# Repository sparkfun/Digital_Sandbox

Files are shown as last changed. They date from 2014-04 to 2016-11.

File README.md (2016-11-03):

Digital_Sandbox
===============

SparkFun Digital Sandbox

[*SparkFun Digital Sandbox (SKU)*](https://www.sparkfun.com/products/12651)

he Digital Sandbox (DS) is a learning platform that engages both the software and hardware worlds.
It’s powered by a microcontroller that can interact with real-world inputs – like light or temperature sensors – while simultaneously controlling LEDs, motors, and other outputs. 

Repository Contents
-------------------

* **/Documentation** - Data files for the Digital Sandbox booklet
* **/Firmware** - Example code for the Digital Sandbox experiment guide
* **/Hardware** - Eagle design files (.brd, .sch)
* **/Production** - Production panel files (.brd)

Documentation
--------------
* **[Hookup Guide](https://learn.sparkfun.com/tutorials/digital-sandbox-arduino-companion)** - Basic hookup guide for the Digital SandBox.
* **[SparkFun Fritzing repo](https://github.com/sparkfun/Fritzing_Parts)** - Fritzing diagrams for SparkFun products.
* **[SparkFun 3D Model repo](https://github.com/sparkfun/3D_Models)** - 3D models of SparkFun products.
* **[SparkFun Graphical Datasheets](https://github.com/sparkfun/Graphical_Datasheets)** -Graphical Datasheets for various SparkFun products.

License Information
-------------------

This product is _**open source**_!

Please review the LICENSE.md file for license information.

If you have any questions or concerns on licensing, please contact techsupport@sparkfun.com.

Distributed as-is; no warranty is given.

- Your friends at SparkFun.

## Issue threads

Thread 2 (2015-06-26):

AREF line is tied directly to battery in

bhuang10000, 2015-06-26:
AREF line is tied directly to the battery IN and the charging circuit. This causes anomalies with the A\D. Suggest tying this to the 3.3V VReg.

ToniCorinne, 2015-06-29:
Since you're internal, please file this as a revision request in Bugzilla. It'll make it easier for us to track that this change has been requested.

Closed 2015-06-29.

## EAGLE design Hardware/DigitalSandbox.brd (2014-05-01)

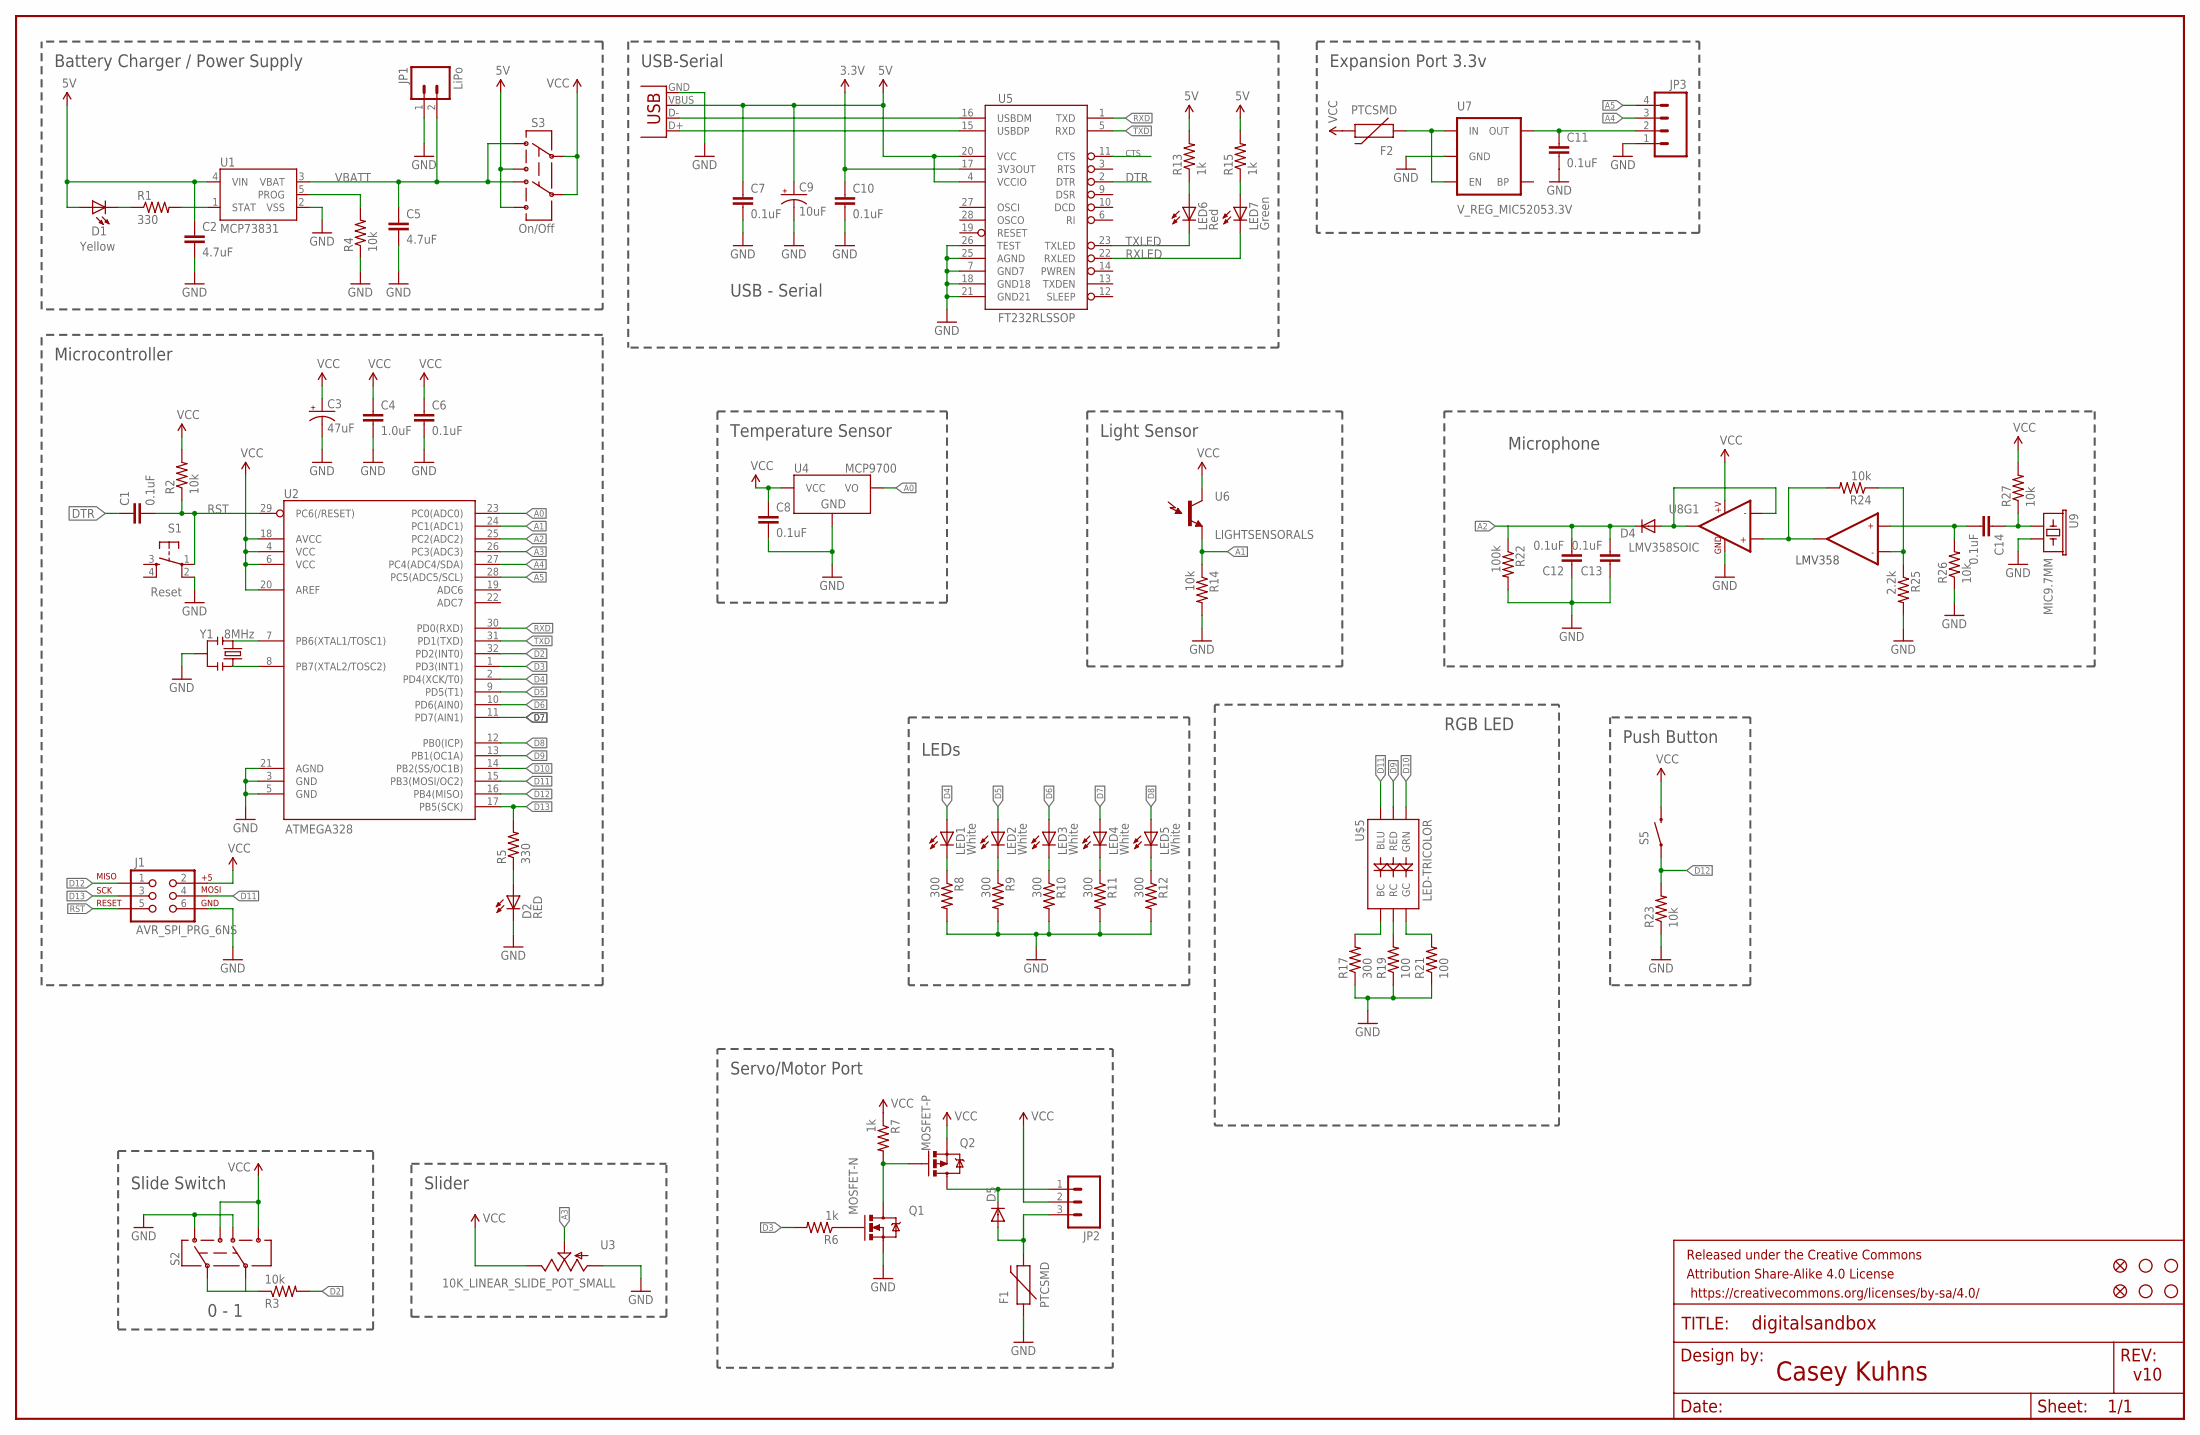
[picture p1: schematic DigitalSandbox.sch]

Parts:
C1, C6, C7, C8, C10, C11, C12, C13, C14: 0.1uF; 0603-CAP
C2, C5: 4.7uF; 0603-CAP
C3: 47uF; EIA3528
C4: 1.0uF; 0603-CAP
C9: 10uF; EIA3216
D1: Yellow; LED-0603
D2: RED; LED-1206
D4, D5: DIODESOD; SOD-323
F1, F2: PTCSMD; PTC-1206
FID1, FID2: FIDUCIAL1X2; FIDUCIAL-1X2
FRAME1: FRAME-LEDGER; CREATIVE_COMMONS
J1: AVR_SPI_PRG_6NS; 2X3-NS
JP1: LiPo; JST-2-SMD
JP2: M03SMD_RA_FEMALE; 1X03_SMD_RA_FEMALE
JP3: M04SMD_STRAIGHT_COMBO; 1X04_SMD_STRAIGHT_COMBO
LED1, LED2, LED3, LED4, LED5: White; LED-1206
LED6: Red; LED-0603
LED7: Green; LED-0603
Q1: MOSFET-N; SOT23
Q2: MOSFET-P; SOT23-3
R1, R5: 330; 0603-RES
R2, R3, R4, R14, R23, R24, R26, R27: 10k; 0603-RES
R6, R7, R13, R15: 1k; 0603-RES
R8, R9, R10, R11, R12, R17: 300; 0603-RES
R19, R21: 100; 0603-RES
R22: 100k; 0603-RES
R25: 2.2k; 0603-RES
S1: Reset; TACTILE_SWITCH_SMD
S2: SWITCH-DPDTAYZ0202; AYZ0202
S3: On/Off; AYZ0202
S5: SWITCH-MOMENTARY-2SMD-4; TACTILE_SWITCH_TALL
STANDOFF1, STANDOFF2, STANDOFF3, STANDOFF4: STAND-OFF
U1: MCP73831; SOT23-5
U2: ATMEGA328; TQFP32-08
U3: 10K_LINEAR_SLIDE_POT_SMALL; C2031N-1A2-B10K-GP
U4: MCP9700; SOT23-3
U5: FT232RLSSOP; SSOP28DB
U6: LIGHTSENSORALS; ALS-PT19
U7: V_REG_MIC52053.3V; SOT23-5
U8: LMV358SOIC; SO08
U9: MIC9.7MM; MIC-9.7MM
U$5: LED-TRICOLOR; PLCC-6-LED
X1: USBSMD; USB-MINIB
Y1: 8MHz; RESONATOR-SMD

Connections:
3.3V: C10.1, U5.17 (3V3OUT)
5V: C2.1, C7.1, C9.A (+), D1.A, R13.2, R15.2, S3.3, S3.6, U1.4 (VIN), U5.4 (VCCIO), U5.20 (VCC), X1.VBUS
A0: U2.23 (PC0(ADC0)), U4.2 (VO)
A1: R14.1, U2.24 (PC1(ADC1)), U6.E (E1)
A2: C12.2, C13.2, D4.C, R22.1, U2.25 (PC2(ADC2))
A3: U2.26 (PC3(ADC3)), U3.1 (S)
A4: JP3.3, U2.27 (PC4(ADC4/SDA))
A5: JP3.4, U2.28 (PC5(ADC5/SCL))
BLUE: R17.2, U$5.CB (BC)
CTS: U5.11 (CTS)
D2: R3.2, U2.32 (PD2(INT0))
D3: R6.2, U2.1 (PD3(INT1))
D4: LED1.A, U2.2 (PD4(XCK/T0))
D5: LED2.A, U2.9 (PD5(T1))
D6: LED3.A, U2.10 (PD6(AIN0))
D7: LED4.A, U2.11 (PD7(AIN1))
D8: LED5.A, U2.12 (PB0(ICP))
D9: U2.13 (PB1(OC1A)), U$5.AR (RED)
D10: U2.14 (PB2(SS/OC1B)), U$5.AG (GRN)
D11: J1.4, U2.15 (PB3(MOSI/OC2)), U$5.AB (BLU)
D12: J1.1, R23.2, S5.A2 (1), U2.16 (PB4(MISO))
D13: J1.3, R5.2, U2.17 (PB5(SCK))
DTR: C1.1, U5.2 (DTR)
GND: C2.2, C3.C (-), C4.2, C5.2, C6.2, C7.2, C8.2, C9.C (-), C10.2, C11.2, C12.1, C13.1, D2.C, F1.1, J1.6, JP1.1 (2), JP3.1, Q1.2 (S), R4.1, R8.2, R9.2, R10.2, R11.2, R12.2, R14.2, R17.1, R19.1, R21.1, R22.2, R23.1, R25.2, R26.1, S1.2, S2.1, S2.4, U1.2 (VSS), U2.3 (GND), U2.5 (GND), U2.21 (AGND), U3.2 (A), U4.3 (GND), U5.7 (GND7), U5.18 (GND18), U5.21 (GND21), U5.25 (AGND), U5.26 (TEST), U7.2 (GND), U8.4 (GND), U9.2, X1.GND, Y1.2
GRN: R21.2, U$5.CG (GC)
unnamed: U2.7 (PB6(XTAL1/TOSC1)), Y1.1
unnamed: D2.A, R5.1
unnamed: U2.8 (PB7(XTAL2/TOSC2)), Y1.3
unnamed: Q1.3 (D), Q2.1 (G), R7.2
unnamed: LED6.A, R13.1
unnamed: LED7.A, R15.1
unnamed: F2.1, U7.1 (IN), U7.3 (EN)
unnamed: D5.C, JP2.1, Q2.3 (D)
unnamed: LED3.C, R10.1
unnamed: Q1.1 (G), R6.1
unnamed: LED4.C, R11.1
unnamed: C11.1, JP3.2, U7.5 (OUT)
unnamed: LED5.C, R12.1
unnamed: R3.1, S2.2, S2.5
unnamed: D5.A, F1.2, JP2.3
unnamed: C14.1, R27.1, U9.1
unnamed: LED1.C, R8.1
unnamed: C14.2, R26.2, U8.5 (+IN2)
unnamed: LED2.C, R9.1
unnamed: R24.1, R25.1, U8.6 (-IN2)
unnamed: D4.A, U8.1 (OUT1), U8.2 (-IN1)
unnamed: R24.2, U8.3 (+IN1), U8.7 (OUT2)
unnamed: D1.C, R1.1
PROG: R4.2, U1.5 (PROG)
RED: R19.2, U$5.CR (RC)
RST: C1.2, J1.5, R2.1, S1.1, U2.29 (PC6(/RESET))
RXD: U2.30 (PD0(RXD)), U5.1 (TXD)
RXLED: LED7.C, U5.22 (RXLED)
STAT: R1.2, U1.1 (STAT)
TXD: U2.31 (PD1(TXD)), U5.5 (RXD)
TXLED: LED6.C, U5.23 (TXLED)
USB_D+: U5.15 (USBDP), X1.D+
USB_D-: U5.16 (USBDM), X1.D-
VBATT: C5.1, JP1.2 (1), S3.1, S3.4, U1.3 (VBAT)
VCC: C3.A (+), C4.1, C6.1, C8.1, F2.2, J1.2, JP2.2, Q2.2 (S), R2.2, R7.1, R27.2, S2.3, S2.6, S3.2, S3.5, S5.B2 (2), U2.4 (VCC), U2.6 (VCC), U2.18 (AVCC), U2.20 (AREF), U3.3 (E), U4.1 (VCC), U6.C (C1), U8.8 (+V)

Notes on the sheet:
LMV358
Battery Charger / Power Supply
USB - Serial
Microcontroller
USB-Serial
Servo/Motor Port
Slider
Push Button
Slide Switch
RGB LED
Expansion Port 3.3v
LEDs
Temperature Sensor
Light Sensor
Microphone
Casey Kuhns
0 - 1
v10

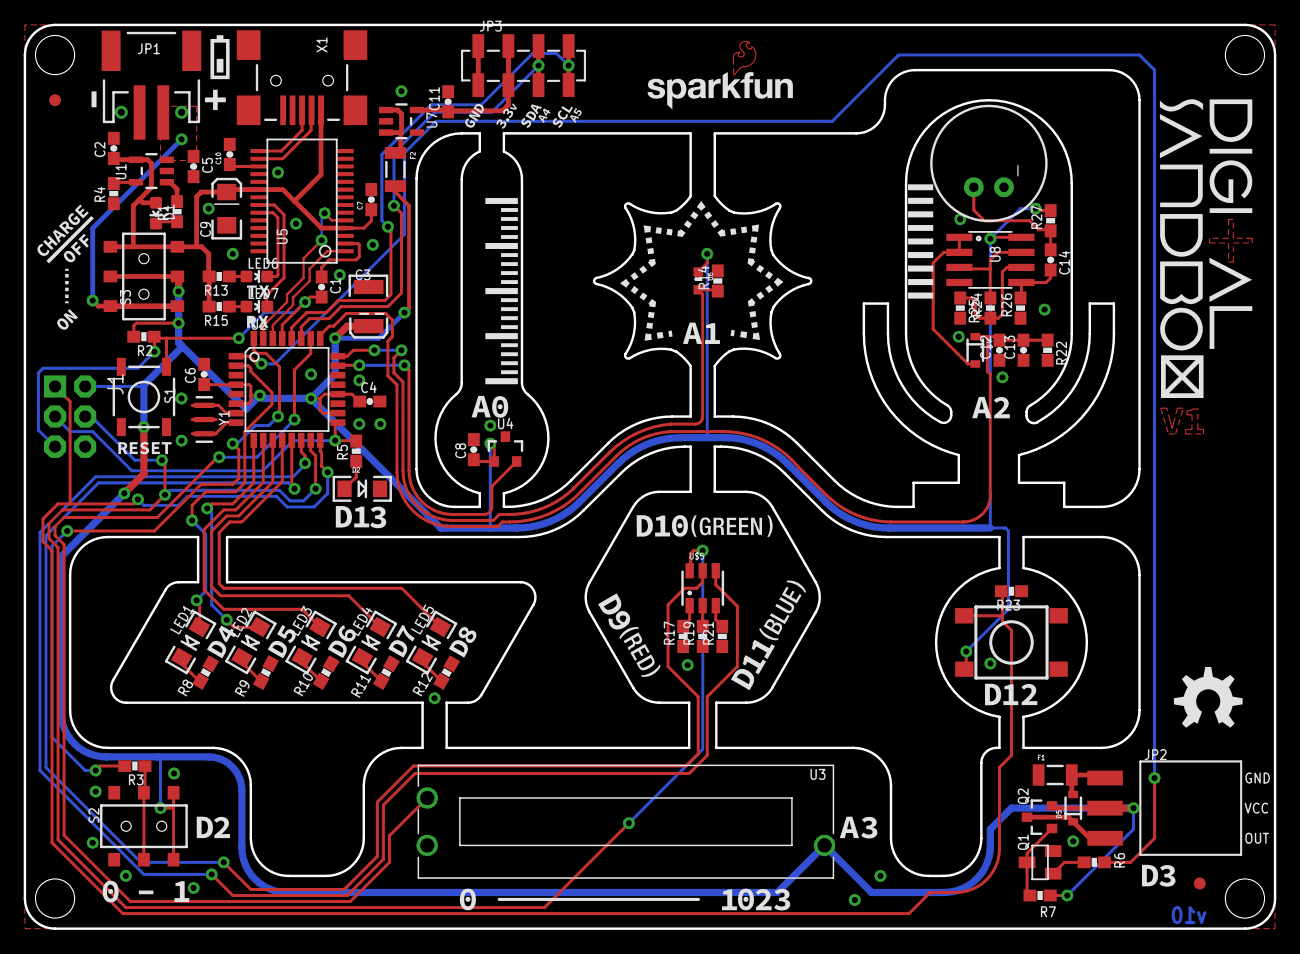
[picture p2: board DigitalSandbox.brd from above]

Board: 2 copper layers, 105.4 x 76.2 mm, 80 parts (0 on the bottom side), 59 nets.

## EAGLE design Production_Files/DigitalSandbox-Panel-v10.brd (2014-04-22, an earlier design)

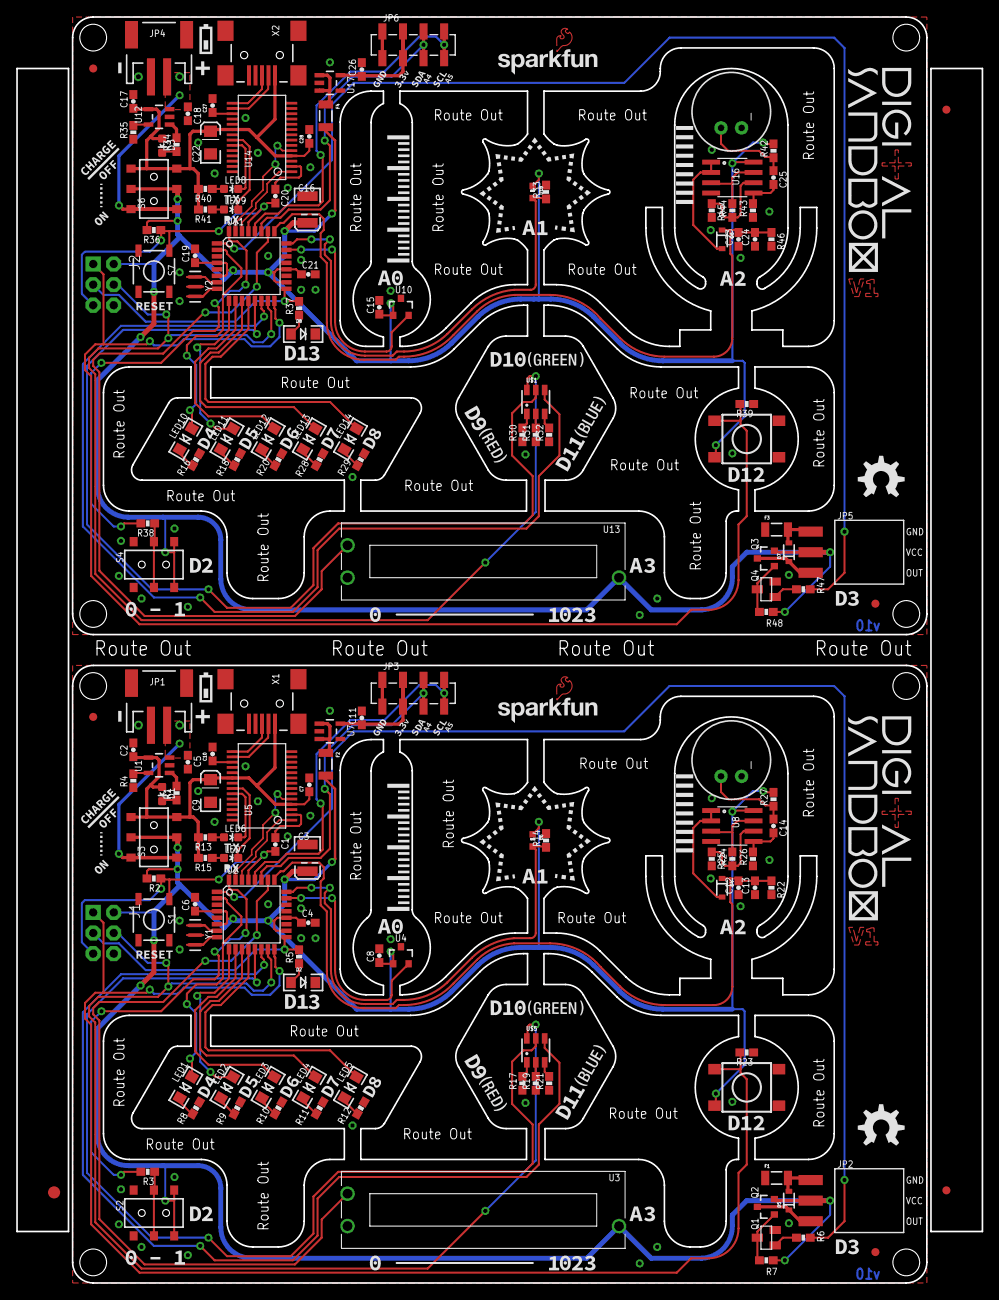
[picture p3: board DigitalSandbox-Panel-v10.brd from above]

Board: 2 copper layers, 119.1 x 156.2 mm, 161 parts (0 on the bottom side), 118 nets.

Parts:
C1, C6, C7, C8, C10, C11, C12, C13, C14, C15, C19, C20, C23, C24, C25, C26, C27, C28: 0.1uF; 0603-CAP
C2, C5, C17, C18: 4.7uF; 0603-CAP
C3, C16: 47uF; EIA3528
C4, C21: 1.0uF; 0603-CAP
C9, C22: 10uF; EIA3216
D1, D3: Yellow; LED-0603
D2, D8: RED; LED-1206
D4, D5, D6, D7: SOD-323
E$1: FIDUCIAL-1.5X3
E$2, E$4: FIDUCIAL-1X2
F1, F2, F3, F4: PTCSMD; PTC-1206
FID1, FID2, FID3, FID4: FIDUCIAL1X2; FIDUCIAL-1X2
J1, J2: AVR_SPI_PRG_6NS; 2X3-NS
JP1, JP4: LiPo; JST-2-SMD
JP2, JP5: 1X03_SMD_RA_FEMALE
JP3, JP6: 1X04_SMD_STRAIGHT_COMBO
LED1, LED2, LED3, LED4, LED5, LED10, LED11, LED12, LED13, LED14: White; LED-1206
LED6, LED8: Red; LED-0603
LED7, LED9: Green; LED-0603
Q1, Q4: MOSFET-N; SOT23
Q2, Q3: MOSFET-P; SOT23-3
R1, R5, R34, R37: 330; 0603-RES
R2, R3, R4, R14, R23, R24, R26, R27, R33, R35, R36, R38, R39, R42, R43, R44: 10k; 0603-RES
R6, R7, R13, R15, R40, R41, R47, R48: 1k; 0603-RES
R8, R9, R10, R11, R12, R16, R17, R18, R20, R28, R29, R30: 300; 0603-RES
R19, R21, R31, R32: 100; 0603-RES
R22, R46: 100k; 0603-RES
R25, R45: 2.2k; 0603-RES
S1, S7: Reset; TACTILE_SWITCH_SMD
S2, S4: AYZ0202
S3, S6: On/Off; AYZ0202
S5, S8: SWITCH-MOMENTARY-2SMD-4; TACTILE_SWITCH_TALL
STANDOFF1, STANDOFF2, STANDOFF3, STANDOFF4, STANDOFF5, STANDOFF6, STANDOFF7, STANDOFF8: STAND-OFF
U1, U12: MCP73831; SOT23-5
U2, U11: ATMEGA328; TQFP32-08
U3, U13: C2031N-1A2-B10K-GP
U4, U10: MCP9700; SOT23-3
U5, U14: FT232RLSSOP; SSOP28DB
U6, U18: LIGHTSENSORALS; ALS-PT19
U7, U17: V_REG_LDOSMD; SOT23-5
U8, U16: LMV358SOIC; SO08
U9, U15: MIC9.7MM; MIC-9.7MM
U$1, U$5: LED-TRICOLOR-SMDPLCC-6-SMD; PLCC-6-LED
X1, X2: USBSMD; USB-MINIB
Y1, Y2: 8MHz; RESONATOR-SMD

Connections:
3.3V: C10.1, U5.17
3.3V1: C27.1, U14.17
5V: C2.1, C7.1, C9.A, D1.A, R13.2, R15.2, S3.3, S3.6, U1.4, U5.4, U5.20, X1.VBUS
5V1: C17.1, C22.A, C28.1, D3.A, R40.2, R41.2, S6.3, S6.6, U12.4, U14.4, U14.20, X2.VBUS
A0: U2.23, U4.2
A1: R14.1, U2.24, U6.E
A2: C12.2, C13.2, D4.C, R22.1, U2.25
A3: U2.26, U3.1
A4: JP3.3, U2.27
A5: JP3.4, U2.28
A6: C23.2, C24.2, D6.C, R46.1, U11.25
A7: U11.26, U13.1
A8: JP6.3, U11.27
A9: JP6.4, U11.28
A10: U10.2, U11.23
A11: R33.1, U11.24, U18.E
BLUE: R17.2, U$5.CB
BLUE1: R30.2, U$1.CB
D1: J2.4, U11.15, U$1.AB
D2: R3.2, U2.32
D3: R6.2, U2.1
D4: LED1.A, U2.2
D5: LED2.A, U2.9
D6: LED3.A, U2.10
D7: LED4.A, U2.11
D8: LED5.A, U2.12
D9: U2.13, U$5.AR
D10: U2.14, U$5.AG
D11: J1.4, U2.15, U$5.AB
D12: J1.1, R23.2, S5.A2, U2.16
D13: J1.3, R5.2, U2.17
D14: J2.3, R37.2, U11.17
D15: LED11.A, U11.9
D16: U11.13, U$1.AR
D17: LED12.A, U11.10
D18: U11.14, U$1.AG
D19: R38.2, U11.32
D20: R47.2, U11.1
D21: LED10.A, U11.2
D22: LED14.A, U11.12
D23: LED13.A, U11.11
D24: J2.1, R39.2, S8.A2, U11.16
DTR: C1.1, U5.2
DTR1: C20.1, U14.2
GND: C2.2, C3.C, C4.2, C5.2, C6.2, C7.2, C8.2, C9.C, C10.2, C11.2, C12.1, C13.1, D2.C, F1.1, J1.6, JP1.1, JP3.1, Q1.2, R4.1, R8.2, R9.2, R10.2, R11.2, R12.2, R14.2, R17.1, R19.1, R21.1, R22.2, R23.1, R25.2, R26.1, S1.2, S2.1, S2.4, U1.2, U2.3, U2.5, U2.21, U3.2, U4.3, U5.7, U5.18, U5.21, U5.25, U5.26, U7.2, U8.4, U9.2, X1.GND, Y1.2
GND1: C15.2, C16.C, C17.2, C18.2, C19.2, C21.2, C22.C, C23.1, C24.1, C26.2, C27.2, C28.2, D8.C, F3.1, J2.6, JP4.1, JP6.1, Q4.2, R16.2, R18.2, R20.2, R28.2, R29.2, R30.1, R31.1, R32.1, R33.2, R35.1, R39.1, R43.1, R45.2, R46.2, S4.1, S4.4, S7.2, U10.3, U11.3, U11.5, U11.21, U12.2, U13.2, U14.7, U14.18, U14.21, U14.25, U14.26, U15.2, U16.4, U17.2, X2.GND, Y2.2
GRN: R21.2, U$5.CG
GRN1: R32.2, U$1.CG
unnamed: U2.7, Y1.1
unnamed: D2.A, R5.1
unnamed: U2.8, Y1.3
unnamed: Q1.3, Q2.1, R7.2
unnamed: LED6.A, R13.1
unnamed: LED7.A, R15.1
unnamed: F2.1, U7.1, U7.3
unnamed: D5.C, JP2.1, Q2.3
unnamed: LED3.C, R10.1
unnamed: Q1.1, R6.1
unnamed: LED4.C, R11.1
unnamed: C11.1, JP3.2, U7.5
unnamed: LED5.C, R12.1
unnamed: R3.1, S2.2, S2.5
unnamed: D5.A, F1.2, JP2.3
unnamed: C14.1, R27.1, U9.1
unnamed: LED1.C, R8.1
unnamed: C14.2, R26.2, U8.5
unnamed: LED2.C, R9.1
unnamed: R24.1, R25.1, U8.6
unnamed: D4.A, U8.1, U8.2
unnamed: LED10.C, R16.1
unnamed: R24.2, U8.3, U8.7
unnamed: LED11.C, R18.1
unnamed: D8.A, R37.1
unnamed: U11.7, Y2.1
unnamed: U11.8, Y2.3
unnamed: D3.C, R34.1
unnamed: D1.C, R1.1
unnamed: LED12.C, R20.1
unnamed: LED13.C, R28.1
unnamed: LED14.C, R29.1
unnamed: R38.1, S4.2, S4.5
unnamed: LED8.A, R40.1
unnamed: LED9.A, R41.1
unnamed: C25.1, R42.1, U15.1
unnamed: C25.2, R43.2, U16.5
unnamed: R44.1, R45.1, U16.6
unnamed: D6.A, U16.1, U16.2
unnamed: R44.2, U16.3, U16.7
unnamed: D7.C, JP5.1, Q3.3
unnamed: Q3.1, Q4.3, R48.2
unnamed: Q4.1, R47.1
unnamed: C26.1, JP6.2, U17.5
unnamed: F4.1, U17.1, U17.3
unnamed: D7.A, F3.2, JP5.3
PROG: R4.2, U1.5
PROG1: R35.2, U12.5
RED: R19.2, U$5.CR
RED1: R31.2, U$1.CR
RST: C1.2, J1.5, R2.1, S1.1, U2.29
RST1: C20.2, J2.5, R36.1, S7.1, U11.29
RXD: U2.30, U5.1
RXD1: U11.30, U14.1
RXLED: LED7.C, U5.22
RXLED1: LED9.C, U14.22
STAT: R1.2, U1.1
STAT1: R34.2, U12.1
TXD: U2.31, U5.5
TXD1: U11.31, U14.5
TXLED: LED6.C, U5.23
TXLED1: LED8.C, U14.23
USB_D+: U5.15, X1.D+
USB_D+1: U14.15, X2.D+
USB_D-: U5.16, X1.D-
USB_D-1: U14.16, X2.D-
VBATT: C5.1, JP1.2, S3.1, S3.4, U1.3
VBATT1: C18.1, JP4.2, S6.1, S6.4, U12.3
VCC: C3.A, C4.1, C6.1, C8.1, F2.2, J1.2, JP2.2, Q2.2, R2.2, R7.1, R27.2, S2.3, S2.6, S3.2, S3.5, S5.B2, U2.4, U2.6, U2.18, U2.20, U3.3, U4.1, U6.C, U8.8
VCC1: C15.1, C16.A, C19.1, C21.1, F4.2, J2.2, JP5.2, Q3.2, R36.2, R42.2, R48.1, S4.3, S4.6, S6.2, S6.5, S8.B2, U10.1, U11.4, U11.6, U11.18, U11.20, U13.3, U16.8, U18.C

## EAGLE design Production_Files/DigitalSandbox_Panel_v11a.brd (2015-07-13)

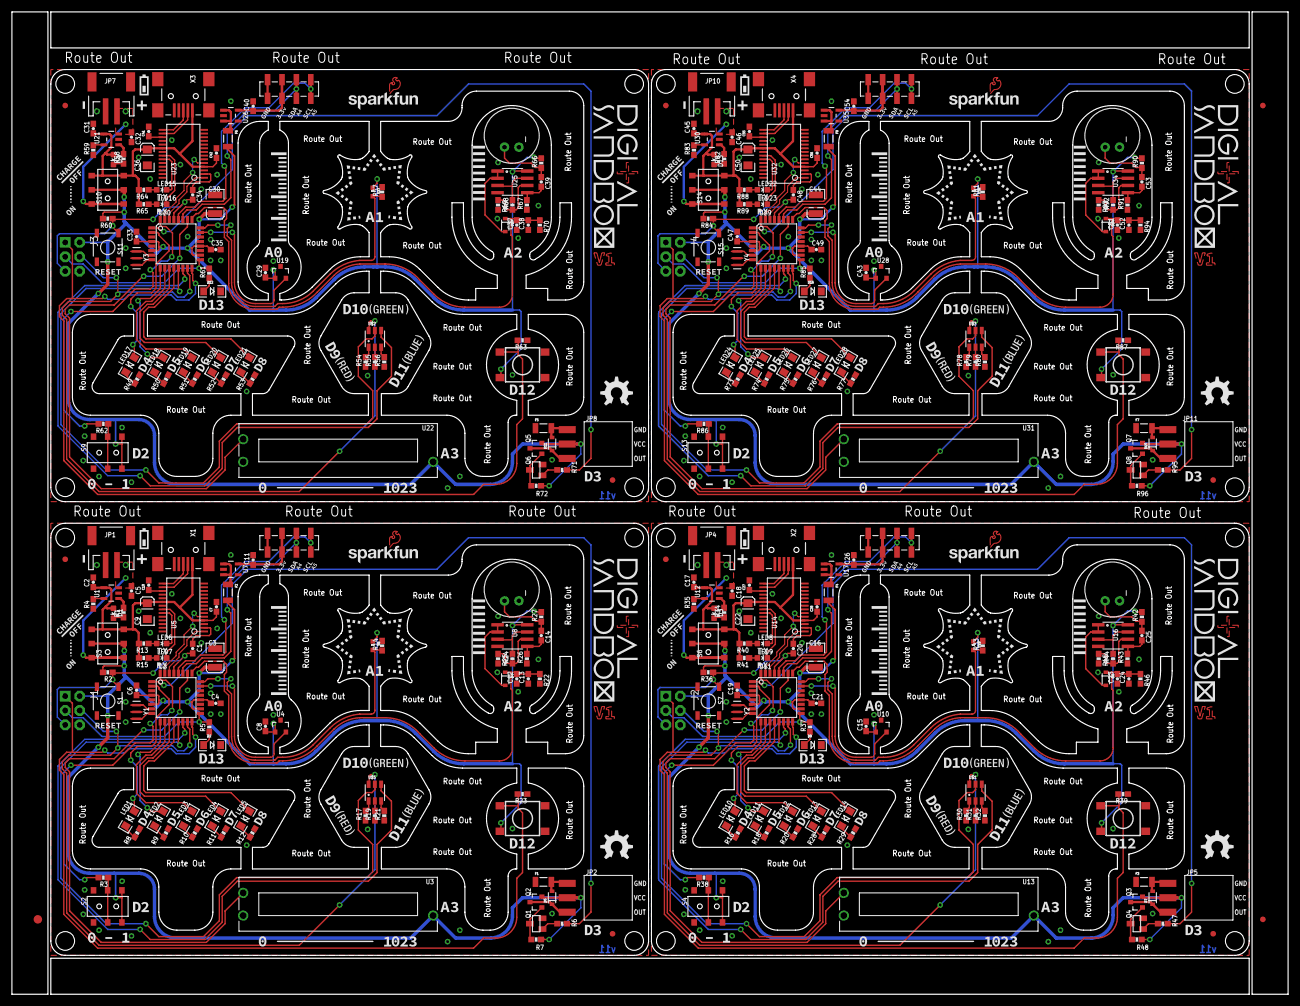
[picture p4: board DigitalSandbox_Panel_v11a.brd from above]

Board: 2 copper layers, 225.0 x 173.2 mm, 319 parts (0 on the bottom side), 236 nets.

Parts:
C1, C6, C7, C8, C10, C11, C12, C13, C14, C15, C19, C20, C23, C24, C25, C26, C27, C28, C29, C33, C34, C37, C38, C39, C40, C41, C42, C43, C47, C48, C51, C52, C53, C54, C55, C56: 0.1uF; 0603-CAP
C2, C5, C17, C18, C31, C32, C45, C46: 4.7uF; 0603-CAP
C3, C16, C30, C44: 47uF; EIA3528
C4, C21, C35, C49: 1.0uF; 0603-CAP
C9, C22, C36, C50: 10uF; EIA3216
D1, D3, D9, D13: Yellow; LED-0603
D2, D8, D12, D16: RED; LED-1206
D4, D5, D6, D7, D10, D11, D14, D15: SOD-323
E$1: FIDUCIAL-1.5X3
E$4, E$5: FIDUCIAL-1X2
F1, F2, F3, F4, F5, F6, F7, F8: PTCSMD; PTC-1206
FID1, FID2, FID3, FID4, FID5, FID6, FID7, FID8: FIDUCIAL1X2; FIDUCIAL-1X2
J1, J2, J3, J4: AVR_SPI_PRG_6NS; 2X3-NS
JP1, JP4, JP7, JP10: LiPo; JST-2-SMD
JP2, JP5, JP8, JP11: 1X03_SMD_RA_FEMALE
JP3, JP6, JP9, JP12: 1X04_SMD_STRAIGHT_COMBO
LED1, LED2, LED3, LED4, LED5, LED10, LED11, LED12, LED13, LED14, LED17, LED18, LED19, LED20, LED21, LED24, LED25, LED26, LED27, LED28: White; LED-1206
LED6, LED8, LED15, LED22: Red; LED-0603
LED7, LED9, LED16, LED23: Green; LED-0603
Q1, Q4, Q6, Q8: MOSFET-N; SOT23
Q2, Q3, Q5, Q7: MOSFET-P; SOT23-3
R1, R5, R34, R37, R58, R61, R82, R85: 330; 0603-RES
R2, R3, R4, R14, R23, R24, R26, R27, R33, R35, R36, R38, R39, R42, R43, R44, R57, R59, R60, R62, R63, R66, R67, R68, R81, R83, R84, R86, R87, R90, R91, R92: 10k; 0603-RES
R6, R7, R13, R15, R40, R41, R47, R48, R64, R65, R71, R72, R88, R89, R95, R96: 1k; 0603-RES
R8, R9, R10, R11, R12, R16, R17, R18, R20, R28, R29, R30, R49, R50, R51, R52, R53, R54, R73, R74, R75, R76, R77, R78: 300; 0603-RES
R19, R21, R31, R32, R55, R56, R79, R80: 100; 0603-RES
R22, R46, R70, R94: 100k; 0603-RES
R25, R45, R69, R93: 2.2k; 0603-RES
S1, S7, S11, S15: Reset; TACTILE_SWITCH_SMD
S2, S4, S9, S13: AYZ0202
S3, S6, S10, S14: On/Off; AYZ0202
S5, S8, S12, S16: SWITCH-MOMENTARY-2SMD-4; TACTILE_SWITCH_TALL
STANDOFF1, STANDOFF2, STANDOFF3, STANDOFF4, STANDOFF5, STANDOFF6, STANDOFF7, STANDOFF8, STANDOFF9, STANDOFF10, STANDOFF11, STANDOFF12, STANDOFF13, STANDOFF14, STANDOFF15, STANDOFF16: STAND-OFF
U1, U12, U21, U30: MCP73831; SOT23-5
U2, U11, U20, U29: ATMEGA328; TQFP32-08
U3, U13, U22, U31: 10K_LINEAR_SLIDE_POT_SMALL; C2031N-1A2-B10K-GP
U4, U10, U19, U28: MCP9700; SOT23-3
U5, U14, U23, U32: FT232RLSSOP; SSOP28DB
U6, U18, U27, U36: LIGHTSENSORALS; ALS-PT19
U7, U17, U26, U35: V_REG_MIC52053.3V; SOT23-5
U8, U16, U25, U34: LMV358SOIC; SO08
U9, U15, U24, U33: MIC9.7MM; MIC-9.7MM
U$1, U$2, U$3, U$5: LED-TRICOLOR; PLCC-6-LED
X1, X2, X3, X4: USBSMD; USB-MINIB
Y1, Y2, Y3, Y4: 8MHz; RESONATOR-SMD

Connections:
3.3V: C10.1, U5.17
3.3V1: C27.1, U14.17
3.3V2: C41.1, U23.17
3.3V3: C55.1, U32.17
5V: C2.1, C7.1, C9.A, D1.A, R13.2, R15.2, S3.3, S3.6, U1.4, U5.4, U5.20, X1.VBUS
5V1: C17.1, C22.A, C28.1, D3.A, R40.2, R41.2, S6.3, S6.6, U12.4, U14.4, U14.20, X2.VBUS
5V2: C31.1, C36.A, C42.1, D9.A, R64.2, R65.2, S10.3, S10.6, U21.4, U23.4, U23.20, X3.VBUS
5V3: C45.1, C50.A, C56.1, D13.A, R88.2, R89.2, S14.3, S14.6, U30.4, U32.4, U32.20, X4.VBUS
A0: U2.23, U4.2
A1: R14.1, U2.24, U6.E
A2: C12.2, C13.2, D4.C, R22.1, U2.25
A3: U2.26, U3.1
A4: JP3.3, U2.27
A5: JP3.4, U2.28
A6: C23.2, C24.2, D6.C, R46.1, U11.25
A7: U11.26, U13.1
A8: JP6.3, U11.27
A9: JP6.4, U11.28
A10: U10.2, U11.23
A11: R33.1, U11.24, U18.E
A12: C37.2, C38.2, D10.C, R70.1, U20.25
A13: U20.26, U22.1
A14: JP9.3, U20.27
A15: JP9.4, U20.28
A16: U19.2, U20.23
A17: R57.1, U20.24, U27.E
A18: C51.2, C52.2, D14.C, R94.1, U29.25
A19: U29.26, U31.1
A20: JP12.3, U29.27
A21: JP12.4, U29.28
A22: U28.2, U29.23
A23: R81.1, U29.24, U36.E
BLUE: R17.2, U$5.CB
BLUE1: R30.2, U$1.CB
BLUE2: R54.2, U$2.CB
BLUE3: R78.2, U$3.CB
D1: J2.4, U11.15, U$1.AB
D2: R3.2, U2.32
D3: R6.2, U2.1
D4: LED1.A, U2.2
D5: LED2.A, U2.9
D6: LED3.A, U2.10
D7: LED4.A, U2.11
D8: LED5.A, U2.12
D9: U2.13, U$5.AR
D10: U2.14, U$5.AG
D11: J1.4, U2.15, U$5.AB
D12: J1.1, R23.2, S5.A2, U2.16
D13: J1.3, R5.2, U2.17
D14: J2.3, R37.2, U11.17
D15: LED11.A, U11.9
D16: U11.13, U$1.AR
D17: LED12.A, U11.10
D18: U11.14, U$1.AG
D19: R38.2, U11.32
D20: R47.2, U11.1
D21: LED10.A, U11.2
D22: LED14.A, U11.12
D23: LED13.A, U11.11
D24: J2.1, R39.2, S8.A2, U11.16
D25: J3.4, U20.15, U$2.AB
D26: J3.3, R61.2, U20.17
D27: LED18.A, U20.9
D28: U20.13, U$2.AR
D29: LED19.A, U20.10
D30: U20.14, U$2.AG
D31: R62.2, U20.32
D32: R71.2, U20.1
D33: LED17.A, U20.2
D34: LED21.A, U20.12
D35: LED20.A, U20.11
D36: J3.1, R63.2, S12.A2, U20.16
D37: J4.4, U29.15, U$3.AB
D38: J4.3, R85.2, U29.17
D39: LED25.A, U29.9
D40: U29.13, U$3.AR
D41: LED26.A, U29.10
D42: U29.14, U$3.AG
D43: R86.2, U29.32
D44: R95.2, U29.1
D45: LED24.A, U29.2
D46: LED28.A, U29.12
D47: LED27.A, U29.11
D48: J4.1, R87.2, S16.A2, U29.16
DTR: C1.1, U5.2
DTR1: C20.1, U14.2
DTR2: C34.1, U23.2
DTR3: C48.1, U32.2
GND: C2.2, C3.C, C4.2, C5.2, C6.2, C7.2, C8.2, C9.C, C10.2, C11.2, C12.1, C13.1, D2.C, F1.1, J1.6, JP1.1, JP3.1, Q1.2, R4.1, R8.2, R9.2, R10.2, R11.2, R12.2, R14.2, R17.1, R19.1, R21.1, R22.2, R23.1, R25.2, R26.1, S1.3, S1.4, S2.1, S2.4, U1.2, U2.3, U2.5, U2.21, U3.2, U4.3, U5.7, U5.18, U5.21, U5.25, U5.26, U7.2, U8.4, U9.2, X1.GND, Y1.2
GND1: C15.2, C16.C, C17.2, C18.2, C19.2, C21.2, C22.C, C23.1, C24.1, C26.2, C27.2, C28.2, D8.C, F3.1, J2.6, JP4.1, JP6.1, Q4.2, R16.2, R18.2, R20.2, R28.2, R29.2, R30.1, R31.1, R32.1, R33.2, R35.1, R39.1, R43.1, R45.2, R46.2, S4.1, S4.4, S7.3, S7.4, U10.3, U11.3, U11.5, U11.21, U12.2, U13.2, U14.7, U14.18, U14.21, U14.25, U14.26, U15.2, U16.4, U17.2, X2.GND, Y2.2
GND2: C29.2, C30.C, C31.2, C32.2, C33.2, C35.2, C36.C, C37.1, C38.1, C40.2, C41.2, C42.2, D12.C, F5.1, J3.6, JP7.1, JP9.1, Q6.2, R49.2, R50.2, R51.2, R52.2, R53.2, R54.1, R55.1, R56.1, R57.2, R59.1, R63.1, R67.1, R69.2, R70.2, S9.1, S9.4, S11.3, S11.4, U19.3, U20.3, U20.5, U20.21, U21.2, U22.2, U23.7, U23.18, U23.21, U23.25, U23.26, U24.2, U25.4, U26.2, X3.GND, Y3.2
GND3: C43.2, C44.C, C45.2, C46.2, C47.2, C49.2, C50.C, C51.1, C52.1, C54.2, C55.2, C56.2, D16.C, F7.1, J4.6, JP10.1, JP12.1, Q8.2, R73.2, R74.2, R75.2, R76.2, R77.2, R78.1, R79.1, R80.1, R81.2, R83.1, R87.1, R91.1, R93.2, R94.2, S13.1, S13.4, S15.3, S15.4, U28.3, U29.3, U29.5, U29.21, U30.2, U31.2, U32.7, U32.18, U32.21, U32.25, U32.26, U33.2, U34.4, U35.2, X4.GND, Y4.2
GRN: R21.2, U$5.CG
GRN1: R32.2, U$1.CG
GRN2: R56.2, U$2.CG
GRN3: R80.2, U$3.CG
unnamed: U2.7, Y1.1
unnamed: D2.A, R5.1
unnamed: U2.8, Y1.3
unnamed: Q1.3, Q2.1, R7.2
unnamed: LED6.A, R13.1
unnamed: LED7.A, R15.1
unnamed: F2.1, U7.1, U7.3
unnamed: D5.C, JP2.1, Q2.3
unnamed: LED3.C, R10.1
unnamed: Q1.1, R6.1
unnamed: LED4.C, R11.1
unnamed: C11.1, JP3.2, U7.5
unnamed: LED5.C, R12.1
unnamed: R3.1, S2.2, S2.5
unnamed: D5.A, F1.2, JP2.3
unnamed: C14.1, R27.1, U9.1
unnamed: LED1.C, R8.1
unnamed: C14.2, R26.2, U8.5
unnamed: LED2.C, R9.1
unnamed: R24.1, R25.1, U8.6
unnamed: D4.A, U8.1, U8.2
unnamed: LED10.C, R16.1
unnamed: R24.2, U8.3, U8.7
unnamed: LED11.C, R18.1
unnamed: D8.A, R37.1
unnamed: U11.7, Y2.1
unnamed: U11.8, Y2.3
unnamed: D3.C, R34.1
unnamed: D1.C, R1.1
unnamed: LED12.C, R20.1
unnamed: LED13.C, R28.1
unnamed: LED14.C, R29.1
unnamed: R38.1, S4.2, S4.5
unnamed: LED8.A, R40.1
unnamed: LED9.A, R41.1
unnamed: C25.1, R42.1, U15.1
unnamed: C25.2, R43.2, U16.5
unnamed: R44.1, R45.1, U16.6
unnamed: D6.A, U16.1, U16.2
unnamed: R44.2, U16.3, U16.7
unnamed: D7.C, JP5.1, Q3.3
unnamed: Q3.1, Q4.3, R48.2
unnamed: Q4.1, R47.1
unnamed: C26.1, JP6.2, U17.5
unnamed: F4.1, U17.1, U17.3
unnamed: D7.A, F3.2, JP5.3
unnamed: LED17.C, R49.1
unnamed: LED18.C, R50.1
unnamed: D12.A, R61.1
unnamed: U20.7, Y3.1
unnamed: U20.8, Y3.3
unnamed: D9.C, R58.1
unnamed: LED19.C, R51.1
unnamed: LED20.C, R52.1
unnamed: LED21.C, R53.1
unnamed: R62.1, S9.2, S9.5
unnamed: LED15.A, R64.1
unnamed: LED16.A, R65.1
unnamed: C39.1, R66.1, U24.1
unnamed: C39.2, R67.2, U25.5
unnamed: R68.1, R69.1, U25.6
unnamed: D10.A, U25.1, U25.2
unnamed: R68.2, U25.3, U25.7
unnamed: D11.C, JP8.1, Q5.3
unnamed: Q5.1, Q6.3, R72.2
unnamed: Q6.1, R71.1
unnamed: C40.1, JP9.2, U26.5
unnamed: F6.1, U26.1, U26.3
unnamed: D11.A, F5.2, JP8.3
unnamed: LED24.C, R73.1
unnamed: LED25.C, R74.1
unnamed: D16.A, R85.1
unnamed: U29.7, Y4.1
unnamed: U29.8, Y4.3
unnamed: D13.C, R82.1
unnamed: LED26.C, R75.1
unnamed: LED27.C, R76.1
unnamed: LED28.C, R77.1
unnamed: R86.1, S13.2, S13.5
unnamed: LED22.A, R88.1
unnamed: LED23.A, R89.1
unnamed: C53.1, R90.1, U33.1
unnamed: C53.2, R91.2, U34.5
unnamed: R92.1, R93.1, U34.6
unnamed: D14.A, U34.1, U34.2
unnamed: R92.2, U34.3, U34.7
unnamed: D15.C, JP11.1, Q7.3
unnamed: Q7.1, Q8.3, R96.2
unnamed: Q8.1, R95.1
unnamed: C54.1, JP12.2, U35.5
unnamed: F8.1, U35.1, U35.3
unnamed: D15.A, F7.2, JP11.3
PROG: R4.2, U1.5
PROG1: R35.2, U12.5
PROG2: R59.2, U21.5
PROG3: R83.2, U30.5
RED: R19.2, U$5.CR
RED1: R31.2, U$1.CR
RED2: R55.2, U$2.CR
RED3: R79.2, U$3.CR
RST: C1.2, J1.5, R2.1, S1.1, U2.29
RST1: C20.2, J2.5, R36.1, S7.1, U11.29
RST2: C34.2, J3.5, R60.1, S11.1, U20.29
RST3: C48.2, J4.5, R84.1, S15.1, U29.29
RXD: U2.30, U5.1
RXD1: U11.30, U14.1
RXD2: U20.30, U23.1
RXD3: U29.30, U32.1
RXLED: LED7.C, U5.22
RXLED1: LED9.C, U14.22
RXLED2: LED16.C, U23.22
RXLED3: LED23.C, U32.22
STAT: R1.2, U1.1
STAT1: R34.2, U12.1
STAT2: R58.2, U21.1
STAT3: R82.2, U30.1
TXD: U2.31, U5.5
TXD1: U11.31, U14.5
TXD2: U20.31, U23.5
TXD3: U29.31, U32.5
TXLED: LED6.C, U5.23
TXLED1: LED8.C, U14.23
TXLED2: LED15.C, U23.23
TXLED3: LED22.C, U32.23
USB_D+: U5.15, X1.D+
USB_D+1: U14.15, X2.D+
USB_D+2: U23.15, X3.D+
USB_D+3: U32.15, X4.D+
USB_D-: U5.16, X1.D-
USB_D-1: U14.16, X2.D-
USB_D-2: U23.16, X3.D-
USB_D-3: U32.16, X4.D-
VBATT: C5.1, JP1.2, S3.1, S3.4, U1.3
VBATT1: C18.1, JP4.2, S6.1, S6.4, U12.3
VBATT2: C32.1, JP7.2, S10.1, S10.4, U21.3
VBATT3: C46.1, JP10.2, S14.1, S14.4, U30.3
VCC: C3.A, C4.1, C6.1, C8.1, F2.2, J1.2, JP2.2, Q2.2, R2.2, R7.1, R27.2, S2.3, S2.6, S3.2, S3.5, S5.B2, U2.4, U2.6, U2.18, U2.20, U3.3, U4.1, U6.C, U8.8
VCC1: C15.1, C16.A, C19.1, C21.1, F4.2, J2.2, JP5.2, Q3.2, R36.2, R42.2, R48.1, S4.3, S4.6, S6.2, S6.5, S8.B2, U10.1, U11.4, U11.6, U11.18, U11.20, U13.3, U16.8, U18.C
VCC2: C29.1, C30.A, C33.1, C35.1, F6.2, J3.2, JP8.2, Q5.2, R60.2, R66.2, R72.1, S9.3, S9.6, S10.2, S10.5, S12.B2, U19.1, U20.4, U20.6, U20.18, U20.20, U22.3, U25.8, U27.C
VCC3: C43.1, C44.A, C47.1, C49.1, F8.2, J4.2, JP11.2, Q7.2, R84.2, R90.2, R96.1, S13.3, S13.6, S14.2, S14.5, S16.B2, U28.1, U29.4, U29.6, U29.18, U29.20, U31.3, U34.8, U36.C

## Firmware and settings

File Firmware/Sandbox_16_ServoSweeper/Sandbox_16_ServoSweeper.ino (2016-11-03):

// Sandbox 16: Servo Sweeper

/* DC motors are great for spinning an object at high speed with no regard for 
   where it starts or stops. For many applications, though, it’s important to 
   precisely control the position of a motor. Wing flaps in a plane, steering 
   mechanisms in RC cars, and robotic arm platforms are applications that 
   benefit from motorized position control. For those applications we ditch the 
   DC motor and whip out the servo!

   This is the first experiment where you'll import an external library. In this
   case we'll be using the Servo library. Follow the comments as we show how the
   library is included and then used.
*/

// Servos are controlled using the Servo LIBRARY. To include a library, use the
// #include "library" statement.
#include <Servo.h>	// Include the servo library

// To use the servo library, we need to create an instance of the Servo class.
// This is like creating a variable of type "Servo". We can call our servo 
// anything -- in this case we'll call it "myServo"
Servo myServo;	// Create an instance of the servo library

// Create variables for our input and ouput components:
const int switchPin = 2;	// Switch is connected to pin 2
const int slidePin = A3;	// Slide pot is connected to A3
const int servoPin = 3;		// Servo is connected to pin 3

void setup()
{
	// Set the switch and slide pot pins as INPUTS.
	pinMode(switchPin, INPUT);
	pinMode(slidePin, INPUT);
	
	// To use the myServo object we created above, we need to attach it to a
	// pin. Use the attach function, and use servoPin as the pin value.
	myServo.attach(servoPin); // Attach the myServo object to our servoPin:
}

void loop()
{
	if (digitalRead(switchPin))	// If the switch is in the "1" position:
	{
		// Read in the value of the slide pot, and map it to our servo's
		// position range (0-180):
		int angle = map(analogRead(slidePin), 0, 1023, 0, 180);
		
		// Use the write function to set the angle of the servo:
		myServo.write(angle);
	}
}

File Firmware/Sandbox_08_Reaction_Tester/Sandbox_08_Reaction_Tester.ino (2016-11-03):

// Sandbox 08: Reaction Tester

/* Computers are great at doing math and automating boring tasks, but everyone 
   knows that their _true_ purpose is to play games. Let's create a game on the 
   Digital Sandbox! In order to control the game we need to add **input**.
   
   Up to this point, our Digital Sandbox experience has been very one-sided. 
   _Output_ to tiny yellow LEDs. _Output_ to larger white LEDs. _Output_ to RGB 
   LEDs. Change the fade value of the _output_. Output, output, output. Let's 
   flip the tables on the Sandbox, and send some **input** to the board!
   
   This experiment introduces the digitalRead([pin]) function. This is the first
   time we'll use a function that RETURNS A VALUE. Instead of simply creating a
   function call and going to the next line, we need to do something with the
   function -- either assign it to a variable or use it in a conditional.
*/

// The led variable should run between 4 and 8. It's used to control the white
// leds (D4-D8), one at a time.
int led = 4;
// The speed variable controls how fast the LEDs cycle from one to the next.
// A larger value, means a slower cycle.
int speed = 100;

// setup()! Time to set up some OUTPUTs...and INPUTs!
void setup()
{
	// Set the button and switch as INPUTs:
	pinMode(2, INPUT);
	pinMode(12, INPUT);
	
	// Set all LEDs as outputs:
	pinMode(4, OUTPUT);
	pinMode(5, OUTPUT);
	pinMode(6, OUTPUT);
	pinMode(7, OUTPUT);
	pinMode(8, OUTPUT);
}

void loop()
{
	// The first if statement sets the SPEED of the game.
	// digitalRead() can either return HIGH or LOW. If the switch is in the "1"
	// position, the digitalRead() function will return HIGH.
	if (digitalRead(2) == HIGH)	// If the switch is set to 1...
	{
		speed = 50;				// ...set speed to 50 (fast)
	}
	else						// Else the switch will be set to 0...
	{
		speed = 150;			// ...so set the speed to 150 (slow)
	}
	
	// The button on pin 12 will be HIGH when pressed and LOW otherwise.
	if (digitalRead(12) == HIGH)	// If the button is pressed
	{
		digitalWrite(led, HIGH);	// Turn the active LED on, nothing else.
	}
	else							// Otherwise, if the button is released
	{
		digitalWrite(led, LOW);		// Turn the active LED off.
		
		led = led + 1;				// Increment the led variable by 1
		if (led > 8)				// If led is out of our range (4-8)
		{
			led = 4;				// Set it back to the bottom (LED 4).
		}
		
		digitalWrite(led, HIGH);	// Turn on the new LED
		
		delay(speed);				// Delay for speed ms.
	}
	
	// The else statement above will take up the majority of the loop() if the
	// button is released. One LED will turn off, the next will turn on, and
	// a short delay will occur before we loop back.
}

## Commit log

2013-10-28 Added files for board.
    Will be handing off to marcom for futrther silk work.
    [DigitalSandbox.brd, DigitalSandbox.sch]
2013-10-28 Fixed file structure
    [DigitalSandbox.brd, DigitalSandbox.sch]
2013-10-28 Removed problem files
    [DigitalSandbox.brd, DigitalSandbox.sch]
2013-11-13 Modified layout according to design review findings. Still working on silk.
    [DigitalSandbox.brd, DigitalSandbox.sch]
2013-11-21 Added silk and moved some components
    [DigitalSandbox.brd, DigitalSandbox.sch]
2013-11-21 fixed numbering issues with resistors
    [DigitalSandbox.brd, DigitalSandbox.sch]
2013-11-21 Added Mosfets and updated numbering
    [DigitalSandbox.brd, DigitalSandbox.sch]
2013-11-22 fixed border width
    [DigitalSandbox.brd]
2013-12-28 Changes Made: 1. Swap Tx-Rx 3. correct stop mask on 2 exposed vias 6. flip default logic for push button (Currently normally high) 9. Change i2c header to meet new standard in the works.
    TODO:
    2. Make programming vias for Production
    4. reverse the direction of the potentiometer and add silk showing "0 - 1024"
    5. Source new push button
    7. Investigate adding pulldown resistors for the nchannel fets that service the RGB led
    8. Investigate a new resistor value for the light sensor to increase sensitivity.
    10. Label pin 13 LED (near the uC).
    [DigitalSandbox.brd, DigitalSandbox.sch]
2014-01-14 Changes Made
    1. Made programming vias for Production
    2. reversed the direction of the potentiometer and added silk showing "0 - 1024"
    3. Replaced Mosfets with NPN transistors to control RGB led
    4. Replaces Light sensor with one used on Weather Shield IC-11836
    5. Labeled pin 13 LED (near the uC).
    TODO
    1. Source new push button with better tactile feedback
    2. Source new RGB Led that is diffused and common cathode (this would eliminate the need for transistors.
    [DigitalSandbox.brd, DigitalSandbox.sch]
2014-01-14 added local fiducials
    [DigitalSandbox.brd, DigitalSandbox.sch]
2014-01-20 added ISP header
    [DigitalSandbox.brd, DigitalSandbox.sch]
2014-01-20 added fixed files
    [DigitalSandbox.brd, DigitalSandbox.sch]
2014-01-21 corrected silk and moved vias to prevent ground plane breaks. Touched up layout of schematic to add tags and remove confusing junctions
    [DigitalSandbox.brd, DigitalSandbox.sch]
2014-01-23 Added testpoints for battery charger
    [DigitalSandbox.brd]
2014-01-23 modified Transistor names to reflect BOM I will add a new part the the LIB soon
    [DigitalSandbox.brd, DigitalSandbox.sch]
2014-02-13 Corrected drill hit on power trace.
    [DigitalSandbox.brd]
2014-03-25 Completed:
    1. D13 led from 0603 yellow to 1206 Red.
    2. Re-order A0 - A2.
    3. Add Flyback diode on Motor port
    4. Change resistor values on LED row to 330ohm to reduce intensity.
    6. Label D3 output for motors and servos
    7. Replace D12 pushbutton with new raised head button.
    8. replace RGB LED with one spec'ed by Nate.
    9. Re-order LED pins on Silk.
    5. Investigate the Microphone circuit to increase output.
    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
    [DigitalSandbox.brd, DigitalSandbox.sch]
2014-04-08 removed power transistors from RGB LED's.
    [DigitalSandbox.brd, DigitalSandbox.sch]
2014-04-08 added Rev number
    [DigitalSandbox.brd, DigitalSandbox.sch]
2014-04-14 reduced size of board by .15 inch in X
    [DigitalSandbox.brd, DigitalSandbox.sch]
2014-04-15 fixed silk
    [DigitalSandbox.brd]
2014-04-15 fixed akward spacing on wires
    [DigitalSandbox.brd]
2014-04-15 moved flame
    [DigitalSandbox.brd]
2014-04-21 Added Sparkle Values.
    [DigitalSandbox.brd, DigitalSandbox.sch]
2014-04-22 created panel v10
    [DigitalSandbox-Panel-v10.brd]
2014-05-01 updated Sparkle ID's
    [DigitalSandbox.brd, DigitalSandbox.sch]
2014-08-04 fixed reset button orientation to work with standard push button
    [DigitalSandbox.brd, DigitalSandbox.sch]
2014-08-05 created panel v11
    [DigitalSandbox-Panel-v11.brd]
2015-07-13 created larger panel (v11a)
    [DigitalSandbox-Panel-v10.brd, DigitalSandbox-Panel-v11.brd, DigitalSandbox_Panel_v11a.brd]
2016-11-03 Adding example sketches from hookup guide, fixing .git files, updating readme
    [Sandbox_00_Setup_Loop.ino, Sandbox_01_Exploring_Blink.ino, Sandbox_02_MultiBlink.ino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]

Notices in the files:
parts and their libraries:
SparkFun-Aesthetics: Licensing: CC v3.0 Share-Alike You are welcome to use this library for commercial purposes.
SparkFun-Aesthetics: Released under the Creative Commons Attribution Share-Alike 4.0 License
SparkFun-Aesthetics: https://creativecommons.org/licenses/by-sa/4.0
